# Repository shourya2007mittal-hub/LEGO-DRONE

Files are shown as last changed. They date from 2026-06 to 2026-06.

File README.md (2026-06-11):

# Flight Controller

I am making a STM32F405RGT6 based flight controller for my drone.and has IMU and barometer and has a USB-B Type. It is designed for 4 motor drone. It has 4 layer PCB

I  made custom drone inspired by LEGO design. I  designed a Custom Microcontroller for the drone as well which is based on STM32F405RGT6
<br>

<br>

## Features

Microcontroller: STM32F405RGT6<br>
IMU Sensor: MPU-6050 / ICM-2098<br>
Barometer: BMP280<br>
Design inspired by LEGO<br>

 ## Schematic & PCB<br>



<br>

# 3d Render<br>



  <br>

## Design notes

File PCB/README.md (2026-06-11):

# Overview

This a 4 layer PCB. In the manufacturing folder, the Gerber, BOM, and position files are available for fabricating the PCB. Parts used are JLCPCB compatible.

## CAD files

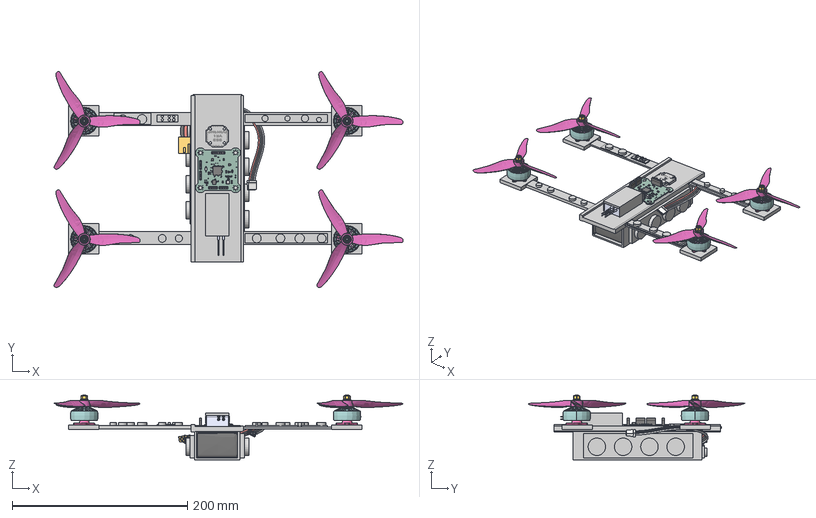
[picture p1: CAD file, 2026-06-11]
CAD/Drone LEGO.step
398.5 x 246.7 x 74.0 mm
Battery Drone

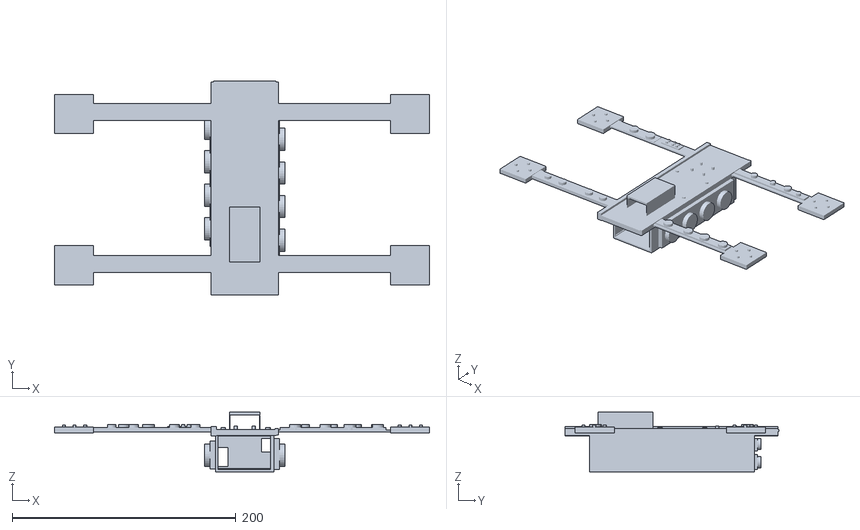
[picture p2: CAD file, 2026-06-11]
Production/LEGO DrONE.stl
335.0 x 191.0 x 53.5

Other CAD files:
CAD/Drone LEGO.f3d

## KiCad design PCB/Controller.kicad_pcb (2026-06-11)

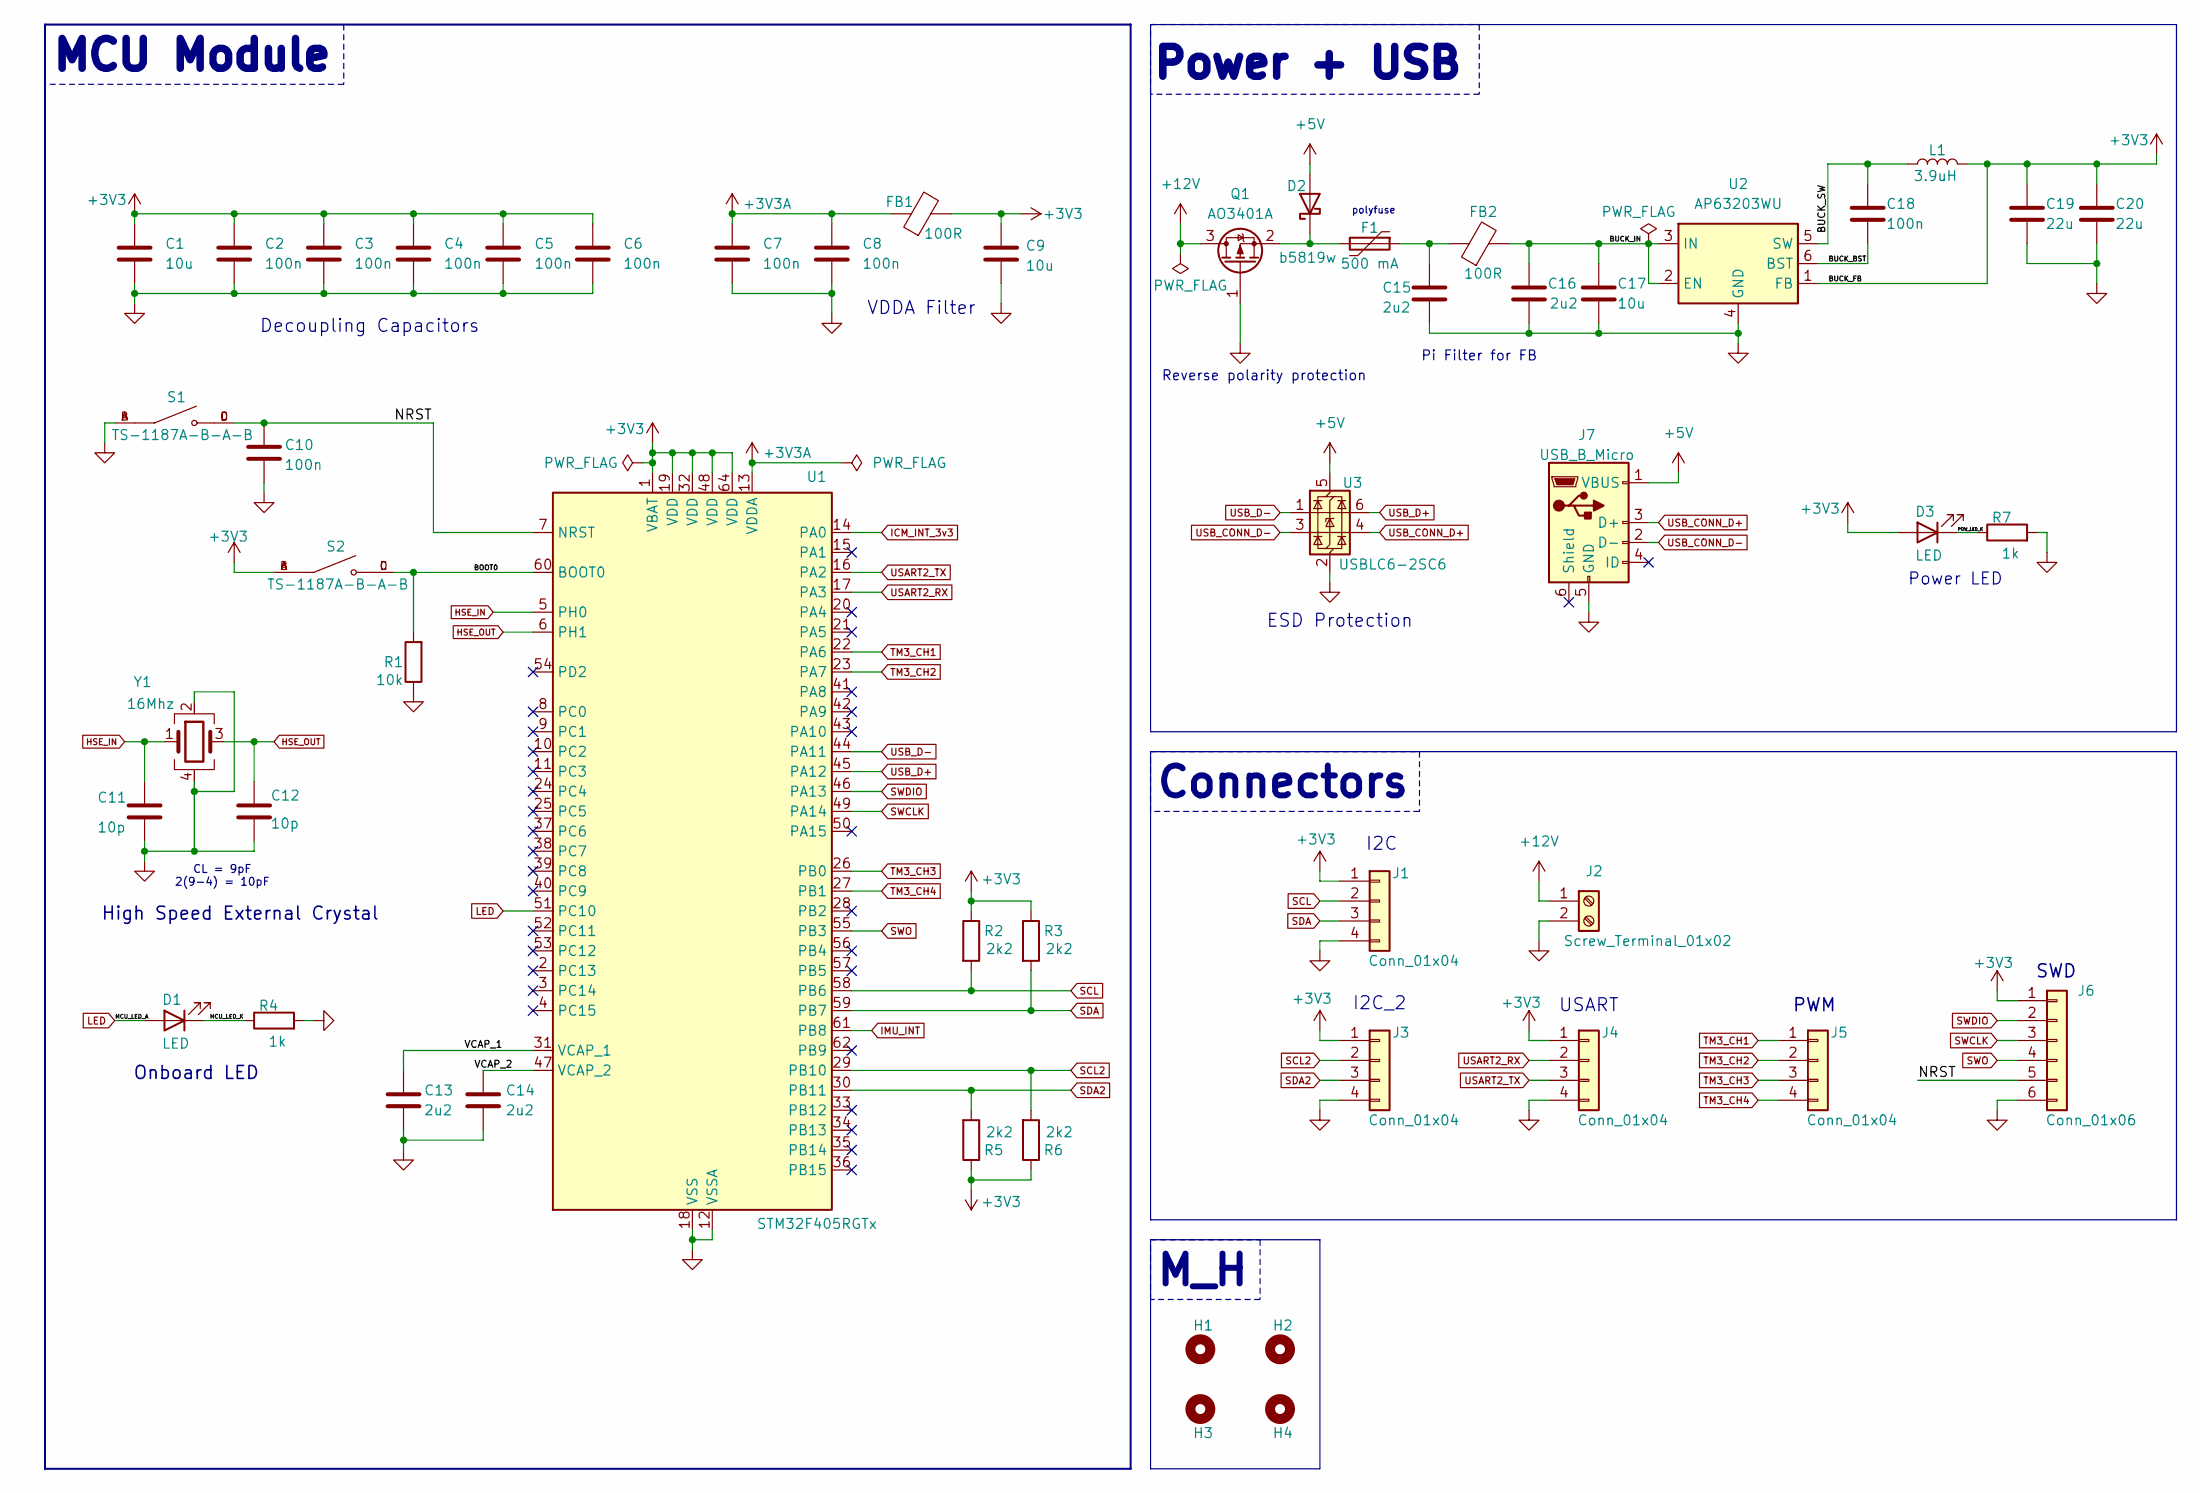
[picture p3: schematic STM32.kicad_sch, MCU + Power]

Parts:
C1, C9, C17: 10u; C_0603_1608Metric
C2, C3, C4, C5, C6, C7, C8, C10: 100n; C_0402_1005Metric
C11, C12: 10p; C_0603_1608Metric
C13, C14, C15, C16: 2u2; C_0603_1608Metric
C18: 100n; C_0805_2012Metric
C19, C20: 22u; C_0805_2012Metric
D1, D3: LED; LED_0603_1608Metric
D2: b5819w; D_SOD-123
F1: 500 mA; Fuse_0603_1608Metric
FB1, FB2: 100R; L_0805_2012Metric
H1, H2, H3, H4: MountingHole; MountingHole_4.3mm_M4_Pad_Via
J1, J3, J4, J5: Conn_01x04; PinSocket_1x04_P2.54mm_Vertical
J2: Screw_Terminal_01x02; TerminalBlock_Xinya_XY308-2.54-2P_1x02_P2.54mm_Horizontal
J6: Conn_01x06; PinSocket_1x06_P2.54mm_Vertical
J7: USB_B_Micro; USB_Micro-B_Amphenol_10118193-0001LF_Horizontal
L1: 3.9uH; L_Sunlord_SWPA4030S
Q1: AO3401A; SOT-23
R1: 10k; R_0603_1608Metric
R2, R3, R5, R6: 2k2; R_0603_1608Metric
R4, R7: 1k; R_0603_1608Metric
S1, S2: TS-1187A-B-A-B; SW_TS-1187A-B-A-B; PARTREV A0
U1: STM32F405RGTx; LQFP-64_10x10mm_P0.5mm
U2: AP63203WU; TSOT-23-6
U3: USBLC6-2SC6; SOT-23-6
Y1: 16Mhz; Crystal_SMD_3225-4Pin_3.2x2.5mm

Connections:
+3V3: C1.1, C2.1, C3.1, C4.1, C5.1, C6.1, C9.1, C19.1, C20.1, D3.2 (A), FB1.2, J1.1, J3.1, J4.1, J6.1, L1.2, R2.1, R3.1, R5.1, R6.1, S2.A, S2.B, U1.1 (VBAT), U1.19 (VDD), U1.32 (VDD), U1.48 (VDD), U1.64 (VDD), U2.1 (FB); also elsewhere on the board
+3V3A: C7.1, C8.1, FB1.1, U1.13 (VDDA)
+5V: D2.2 (A), J7.1 (VBUS), U3.5 (VBUS)
+12V: J2.1, Q1.3 (D)
/STM32/BOOT0: R1.2, S2.C, S2.D, U1.60 (BOOT0)
/STM32/BUCK_BST: C18.2, U2.6 (BST)
/STM32/BUCK_IN: C16.1, C17.1, FB2.2, U2.2 (EN), U2.3 (IN)
/STM32/BUCK_SW: C18.1, L1.1, U2.5 (SW)
/STM32/MCU_LED_K: D1.1 (K), R4.1
/STM32/NRST: C10.1, J6.5, S1.C, S1.D, U1.7 (NRST)
/STM32/POW_LED_K: D3.1 (K), R7.1
/STM32/VCAP_1: C13.1, U1.31 (VCAP_1)
/STM32/VCAP_2: C14.1, U1.47 (VCAP_2)
GND: C1.2, C2.2, C3.2, C4.2, C5.2, C6.2, C7.2, C8.2, C9.2, C10.2, C11.2, C12.2, C13.2, C14.2, C15.2, C16.2, C17.2, C19.2, C20.2, H1.1, H2.1, H3.1, H4.1, J1.4, J2.2, J3.4, J4.4, J6.6, J7.5 (GND), Q1.1 (G), R1.1, R4.2, R7.2, S1.A, S1.B, U1.12 (VSSA), U1.18 (VSS), U1.63 (VSS), U2.4 (GND), U3.2 (GND), Y1.2, Y1.4; also elsewhere on the board
HSE_IN: C11.1, U1.5 (PH0), Y1.1
HSE_OUT: C12.1, U1.6 (PH1), Y1.3
ICM_INT_3v3: U1.14 (PA0); also elsewhere on the board
IMU_INT: U1.61 (PB8); also elsewhere on the board
LED: D1.2 (A), U1.51 (PC10)
unnamed: C15.1, F1.1, FB2.1
unnamed: D2.1 (K), F1.2, Q1.2 (S)
SCL: J1.2, R2.2, U1.58 (PB6); also elsewhere on the board
SCL2: J3.2, R6.2, U1.29 (PB10); also elsewhere on the board
SDA: J1.3, R3.2, U1.59 (PB7); also elsewhere on the board
SDA2: J3.3, R5.2, U1.30 (PB11); also elsewhere on the board
SWCLK: J6.3, U1.49 (PA14)
SWDIO: J6.2, U1.46 (PA13)
SWO: J6.4, U1.55 (PB3)
TM3_CH1: J5.1, U1.22 (PA6)
TM3_CH2: J5.2, U1.23 (PA7)
TM3_CH3: J5.3, U1.26 (PB0)
TM3_CH4: J5.4, U1.27 (PB1)
USART2_RX: J4.2, U1.17 (PA3)
USART2_TX: J4.3, U1.16 (PA2)
USB_CONN_D+: J7.3 (D+), U3.4 (I/O2)
USB_CONN_D-: J7.2 (D-), U3.3 (I/O2)
USB_D+: U1.45 (PA12), U3.6 (I/O1)
USB_D-: U1.44 (PA11), U3.1 (I/O1)

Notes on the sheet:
polyfuse
ESD Protection
Decoupling Capacitors
CL = 9pF 2(9-4) = 10pF
VDDA Filter
Onboard LED
USART
M_H
Pi Filter for FB
I2C
SWD
High Speed External Crystal
Power LED
PWM
Reverse polarity protection
MCU Module
Connectors
Power + USB
I2C_2

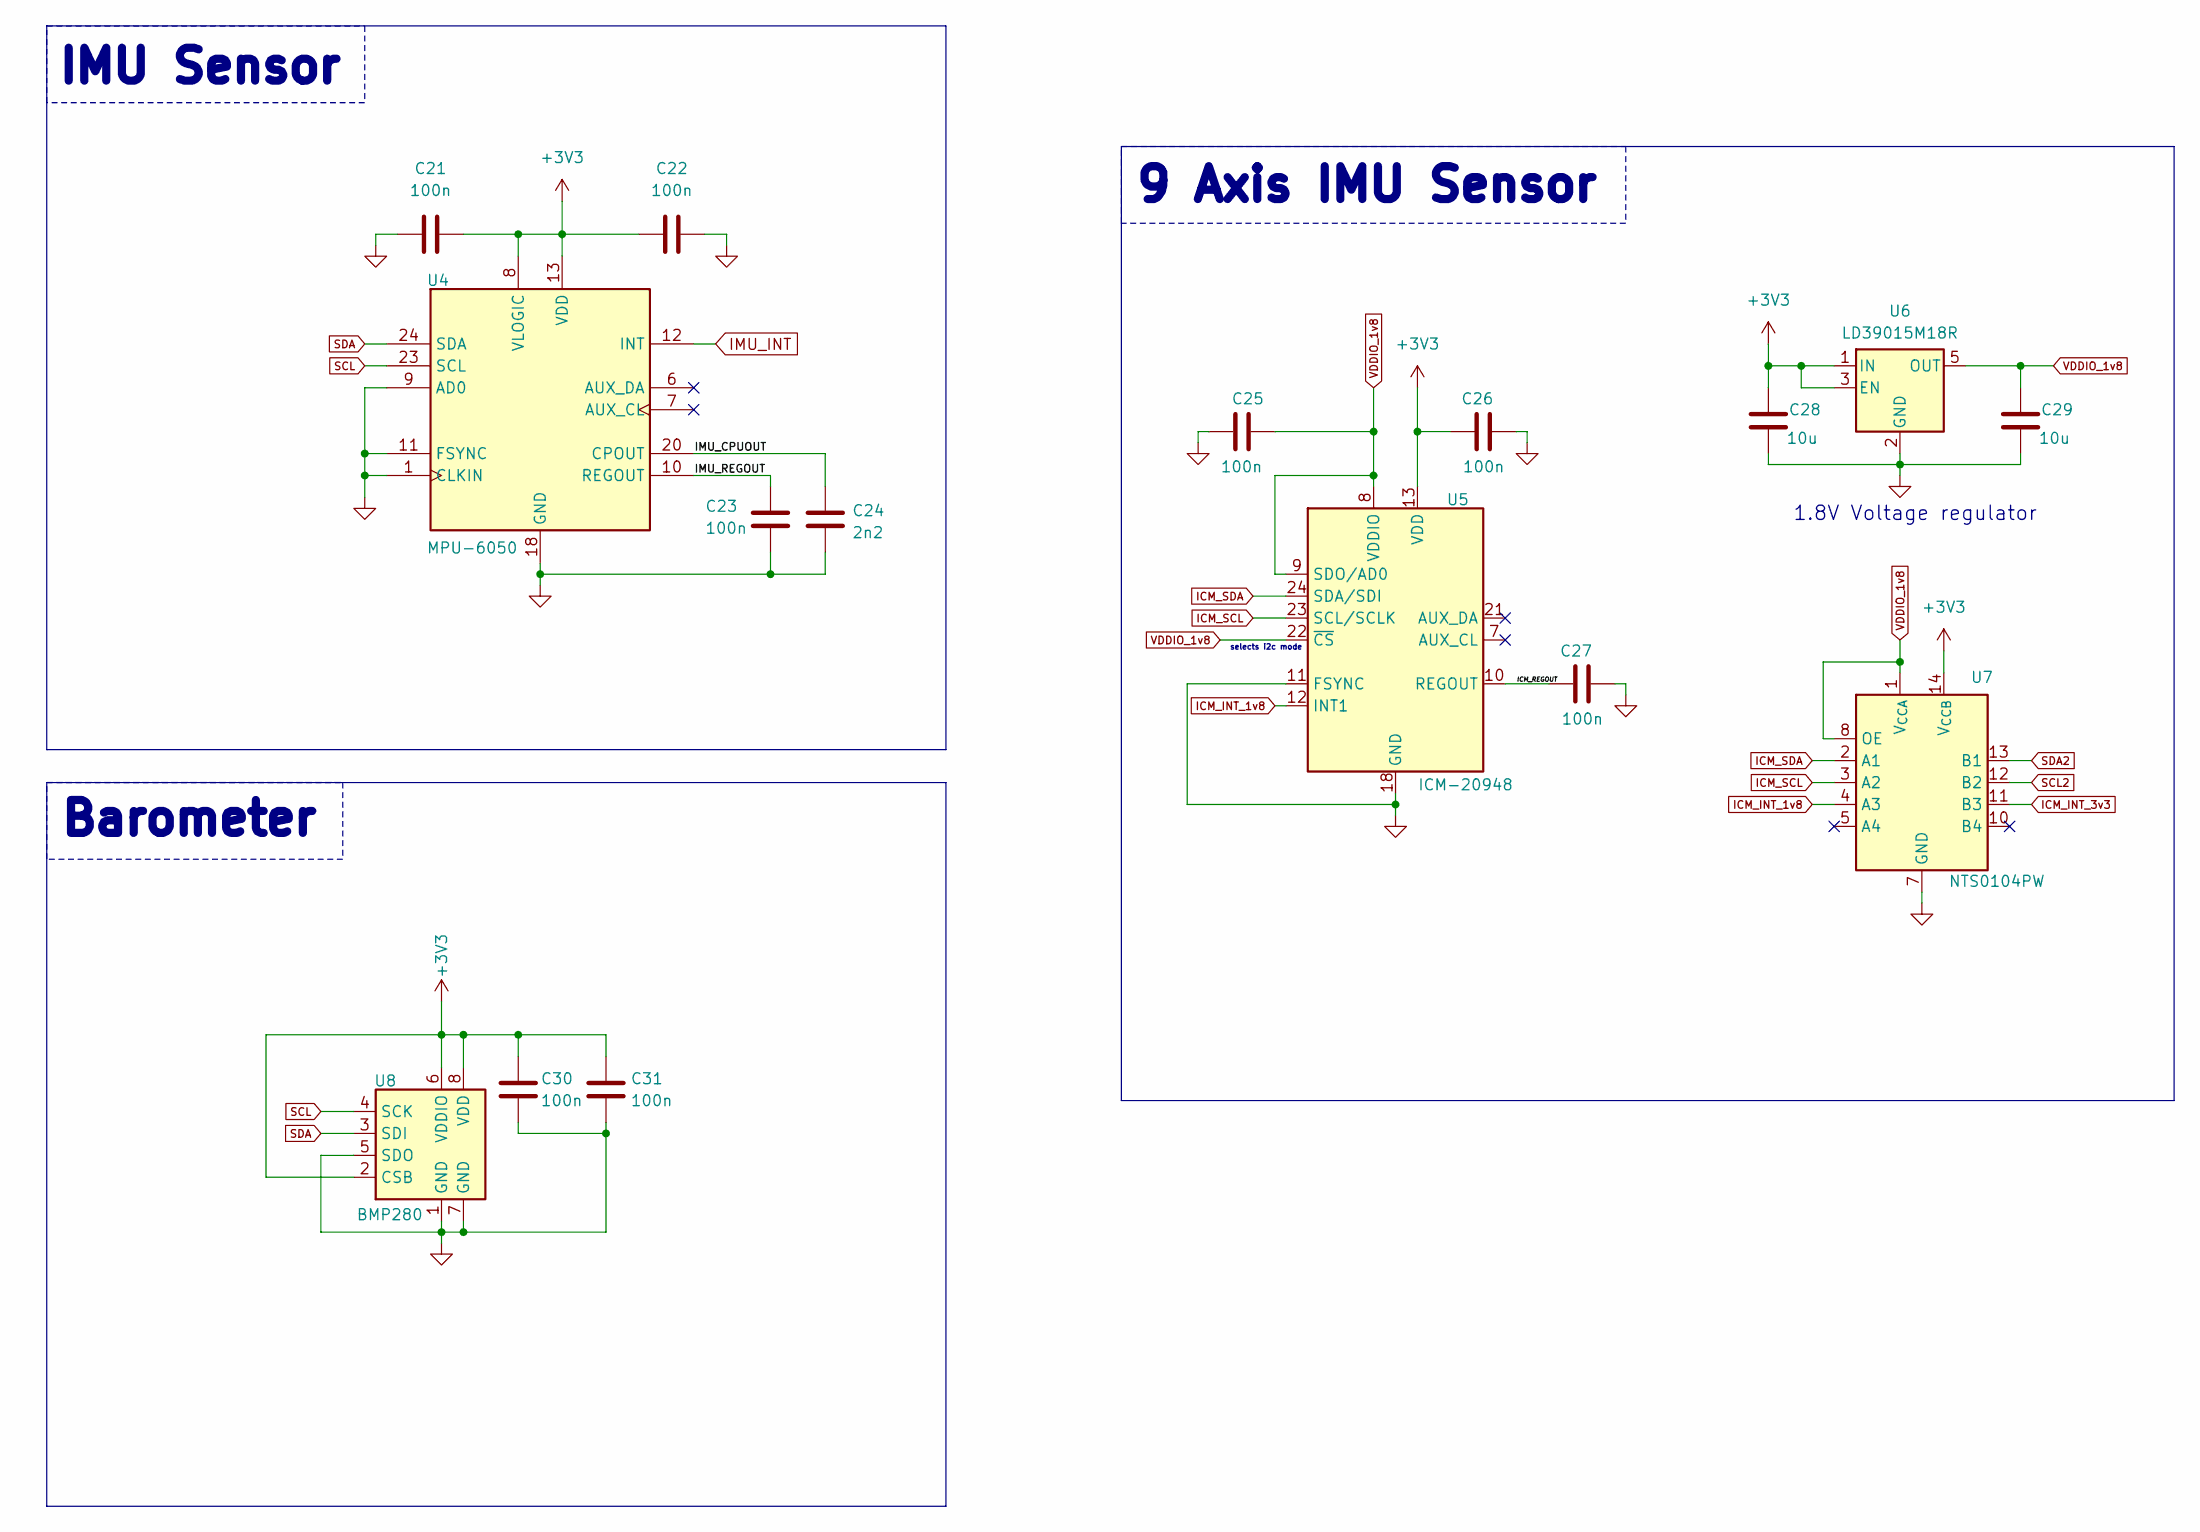
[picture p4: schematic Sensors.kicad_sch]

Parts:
C21, C22, C23, C25, C26, C27, C30, C31: 100n; C_0402_1005Metric
C24: 2n2; C_0603_1608Metric
C28, C29: 10u; C_0603_1608Metric
U4: MPU-6050; InvenSense_QFN-24_4x4mm_P0.5mm
U5: ICM-20948; InvenSense_QFN-24_3x3mm_P0.4mm
U6: LD39015M18R; SOT-23-5
U7: NTS0104PW; TSSOP-14_4.4x5mm_P0.65mm
U8: BMP280; Bosch_LGA-8_2x2.5mm_P0.65mm_ClockwisePinNumbering

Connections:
+3V3: C21.2, C22.1, C26.1, C28.1, C30.1, C31.2, U4.8 (VLOGIC), U4.13 (VDD), U5.13 (VDD), U6.1 (IN), U6.3 (EN), U7.14 (V_{CCB}), U8.2 (CSB), U8.6 (VDDIO), U8.8 (VDD); also elsewhere on the board
/Sensors/ICM_REGOUT: C27.1, U5.10 (REGOUT)
/Sensors/IMU_CPUOUT: C24.1, U4.20 (CPOUT)
/Sensors/IMU_REGOUT: C23.1, U4.10 (REGOUT)
GND: C21.1, C22.2, C23.2, C24.2, C25.2, C26.2, C27.2, C28.2, C29.2, C30.2, C31.1, U4.1 (CLKIN), U4.9 (AD0), U4.11 (FSYNC), U4.18 (GND), U5.11 (FSYNC), U5.18 (GND), U5.20 (GND), U6.2 (GND), U7.7 (GND), U8.1 (GND), U8.5 (SDO), U8.7 (GND); also elsewhere on the board
ICM_INT_1v8: U5.12 (INT1), U7.4 (A3)
ICM_INT_3v3: U7.11 (B3); also elsewhere on the board
ICM_SCL: U5.23 (SCL/SCLK), U7.3 (A2)
ICM_SDA: U5.24 (SDA/SDI), U7.2 (A1)
IMU_INT: U4.12 (INT); also elsewhere on the board
SCL: U4.23 (SCL), U8.4 (SCK); also elsewhere on the board
SCL2: U7.12 (B2); also elsewhere on the board
SDA: U4.24 (SDA), U8.3 (SDI); also elsewhere on the board
SDA2: U7.13 (B1); also elsewhere on the board
VDDIO_1v8: C25.1, C29.1, U5.8 (VDDIO), U5.9 (SDO/AD0), U5.22 (~CS), U6.5 (OUT), U7.1 (V_{CCA}), U7.8 (OE)

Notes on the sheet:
9 Axis IMU Sensor
1.8V Voltage regulator
IMU Sensor
Barometer
selects i2c mode

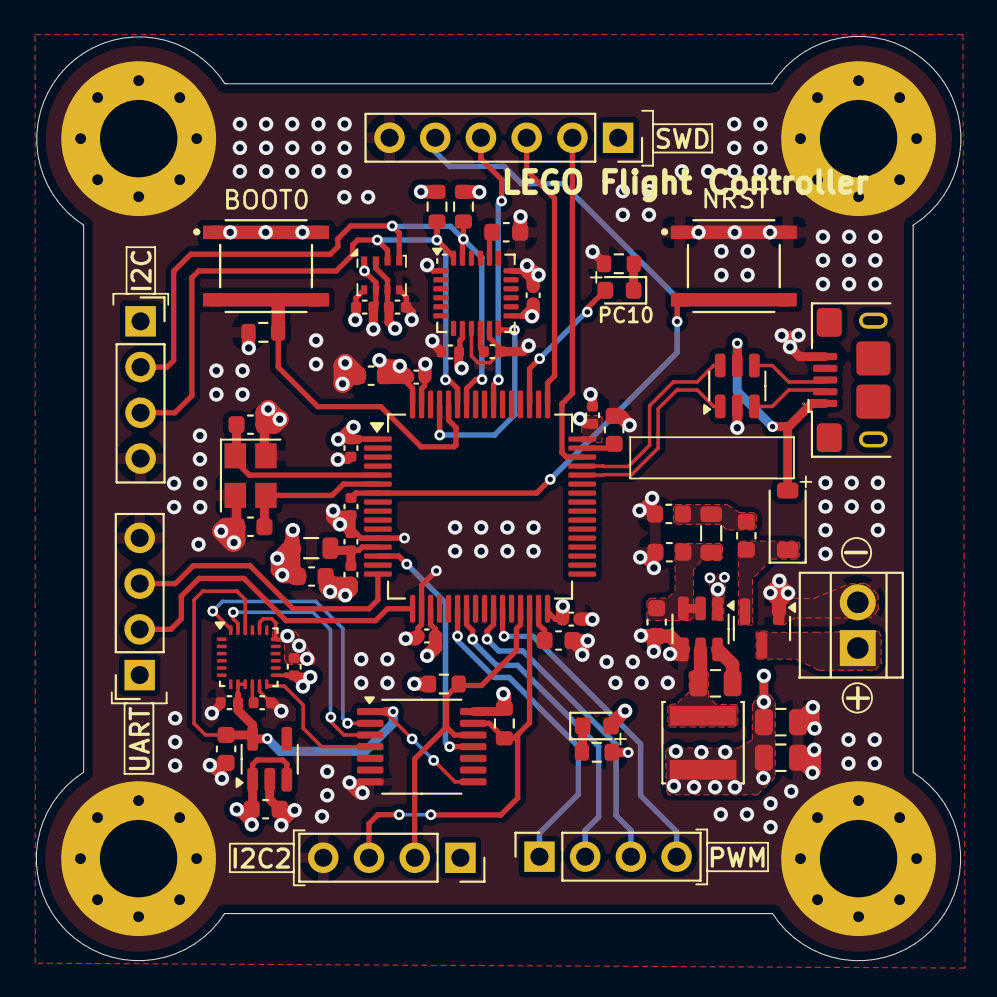
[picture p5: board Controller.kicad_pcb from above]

Board: 4 copper layers, 51.4 x 51.3 mm, 68 parts (0 on the bottom side), 45 nets.
